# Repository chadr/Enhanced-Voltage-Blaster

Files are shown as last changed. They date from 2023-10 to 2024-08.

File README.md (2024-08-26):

# Enhanced Voltage Blaster
 A (slightly) enhanced version of the original Voltage Blaster by PhilsComputerLab and Necroware [here](https://youtu.be/y1-0giyLQIY).

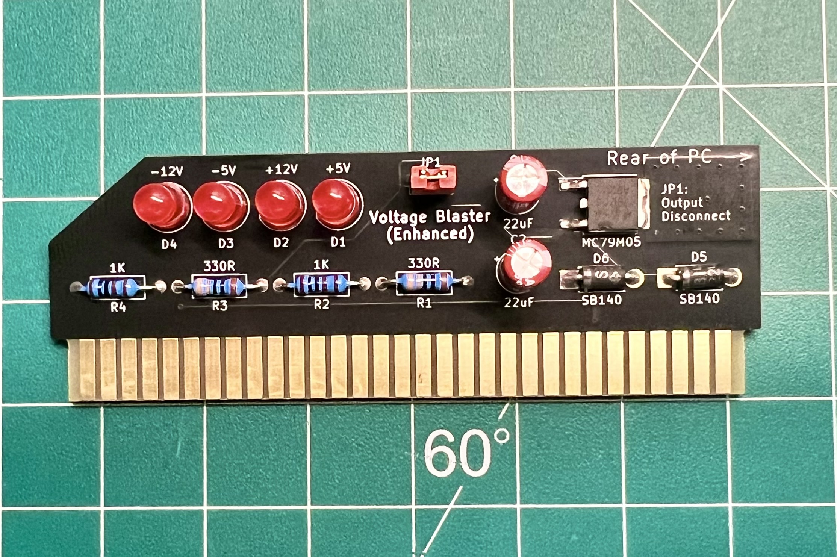
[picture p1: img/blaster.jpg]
Finished Voltage Blaster


**Enhancements:**
* Diodes protect regulator from reverse polarity and reverse bias. Prevents soundcard-frying over voltage.
* Four LEDs show presence of the four main power rails on the ISA bus.
* Dual copper heatsink pads embedded into PCB design to keep regulator cool.
* Jumper to disable Voltage Blaster without removal. Can be used to verify lack of (-)5V on ISA bus.

The datasheet for the 79xx series negative regulators strongly recommend two protection diodes. PCs get shutdown suddenly and sound cards have lots of capacitance. The exact two situations described here.
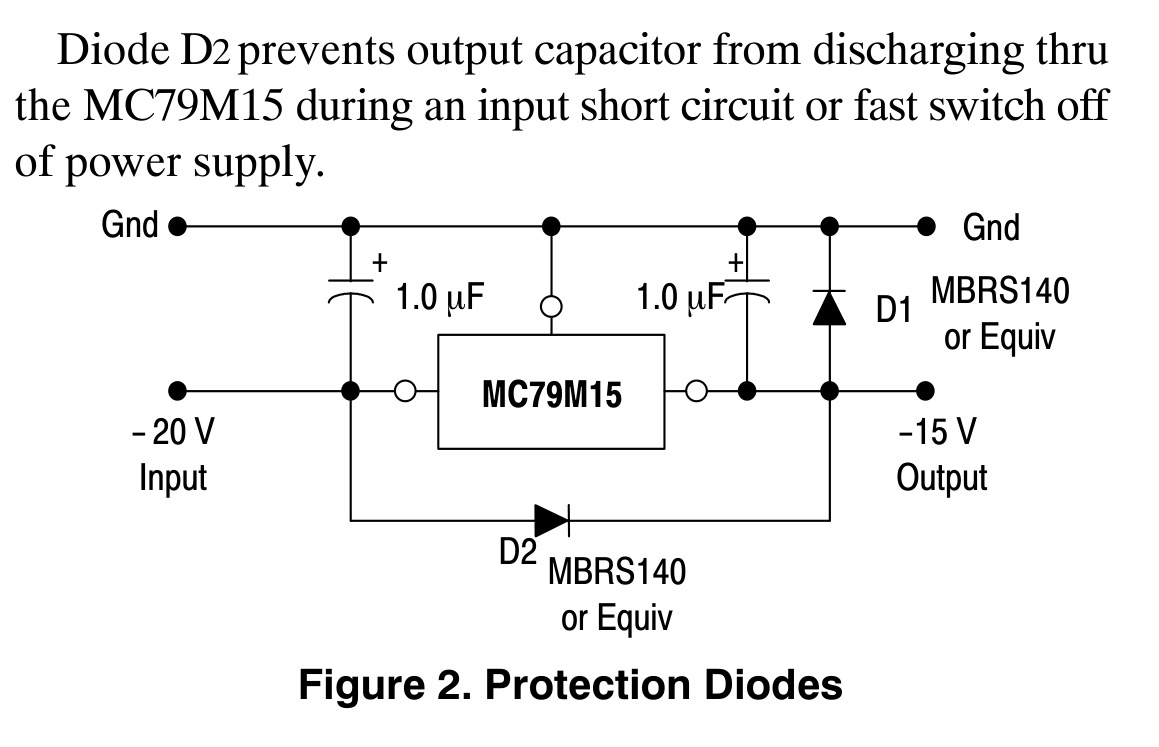
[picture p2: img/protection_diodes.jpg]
Protection diode info


**Bill of Materials**
**Item**|**Qty**|**MFG Part Num**|**Mouser Part Num**
:-----:|:-----:|:-----:|:-----:
Neg 5V Linear Regulator|1|MC79M05CDT|863-MC79M05CDT
22uF 35V Electrolytic Capacitor|2|860010572003|710-860010572003
5mm Red LED Diffused|4|WP7113ID|604-WP7113ID
330R Metal Film Resistor 1%|2|MFR-25FRF52-330R|603-MFR-25FRF52-330R
1K Metal Film Resistor 1%|2|MFR-25FRF52-1K|603-MFR-25FRF52-1K
Schottky Diode 40 Volt 1.0 Amp|2|SB140-E3/73|625-SB140-E3/73



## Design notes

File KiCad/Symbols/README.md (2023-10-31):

# Symbols
A place to store custom Kicad symbols that I have created. Use at your own risk. You should vet your own use of these symbols for suitability and accuracy.

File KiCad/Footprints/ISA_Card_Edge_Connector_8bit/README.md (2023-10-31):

# ISA_Card_Edge_Connector_8bit
A Kicad footprint describing the 8-bit ISA card edge connector.

## Revision 1:
- Added F.Mask and B.Mask areas over card edge fingers, so they do not need to be added manually on a board design.
- Added some distance measurements to the "Eco2.User" layer, as well as a suggested grid spacing, to make it easier to set the edge connector width on the Edge.Cuts layer.

Rev1 Image

## Revision 0:
- First release of the footprint.
- Footprint origin is aligned to the bottom centre of Pad A01 (Pad B01) of the corresponding 8bit ISA card edge connector.
- Board edge guides are on the "Eco1.User" layer. Take care as they are strange decimal fractions.
- Board edge guide duplicated on the "F.Fab" layer adjacent to the card edge connector (can't remember why I did this...)
- See corresponding ISA card edge reference drawing for exact board edge locations.
- Corresponding Keystone 9202 hole location reference shown as a cross in the upper right hand of the symbol on the "Eco1.User" layer.

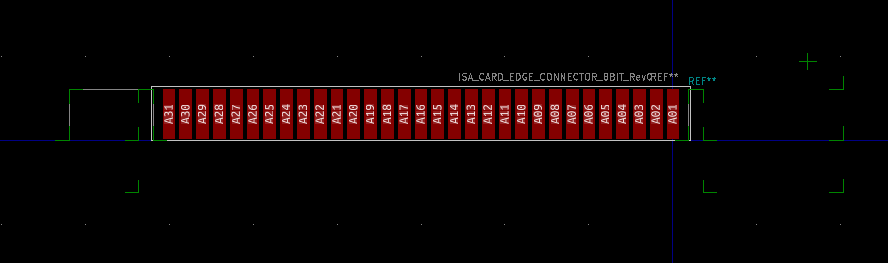
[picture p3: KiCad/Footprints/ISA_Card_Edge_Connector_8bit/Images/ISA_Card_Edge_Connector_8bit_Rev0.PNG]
Rev0 Image


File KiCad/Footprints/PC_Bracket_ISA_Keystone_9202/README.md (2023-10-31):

# PC_Bracket_ISA_Keystone_9202
A Kicad footprint describing the Keystone 9202 mounting bracket, referenced to the bottom of pad A1 of the 8-bit ISA card edge connector.

## Revision 1:
- Added a reference for the location of protruding connectors to the "Cmts.User" layer.
- Added maximum permissible upper board edge reference to the "Eco1.User" layer.

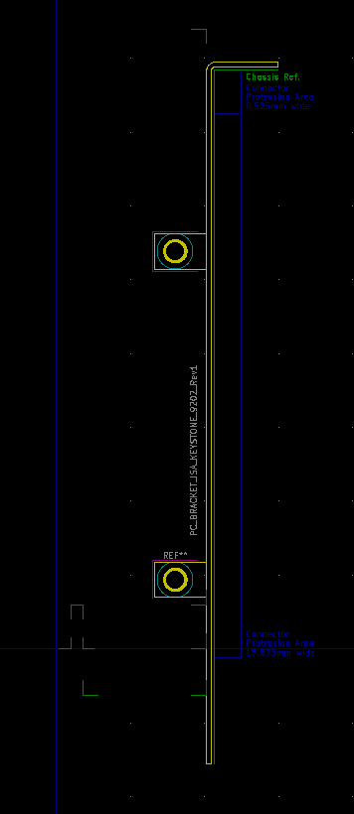
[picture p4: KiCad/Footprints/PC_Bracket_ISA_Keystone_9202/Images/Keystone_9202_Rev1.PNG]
Rev1 Image

## Revision 0:
- First release of the footprint.
- Footprint origin is aligned to the bottom centre of Pad A01 (Pad B01) of the corresponding 8bit ISA card edge connector.
- Board edge guides are on the "Eco1.User" layer. Take care as they are strange decimal fractions.
- See corresponding ISA card edge reference drawing for exact board edge locations.
- Bracket physical outline is on the "Eco2.User" layer.
- Board mounting holes presented as circular plated through holes, 3.2mm dia. "Pin 1" located towards bottom of bracket. "Pin 2" located towards top of bracket. 

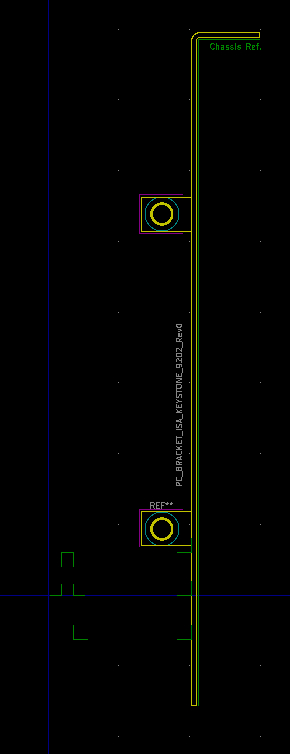
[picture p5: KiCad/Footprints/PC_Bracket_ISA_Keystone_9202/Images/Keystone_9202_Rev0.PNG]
Rev0 Image


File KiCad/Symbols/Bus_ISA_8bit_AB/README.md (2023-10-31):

# Bus_ISA_8bit_AB Symbol
A Kicad symbol for use with the ISA_Card_Edge_Connector_8bit footprint.

## Revision 0:
- First release of the symbol.

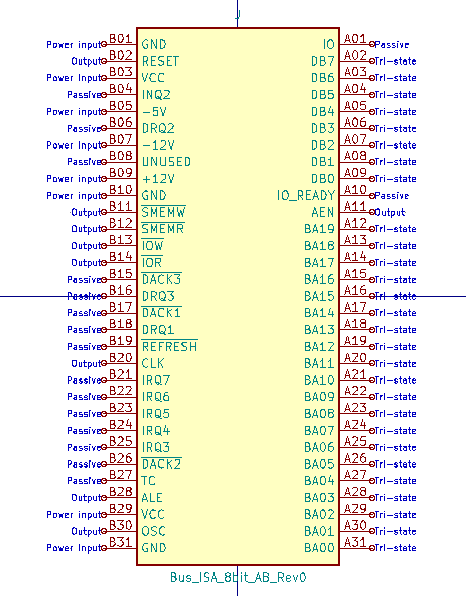
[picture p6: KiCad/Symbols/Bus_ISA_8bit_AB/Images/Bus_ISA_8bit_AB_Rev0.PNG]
Rev0 Image


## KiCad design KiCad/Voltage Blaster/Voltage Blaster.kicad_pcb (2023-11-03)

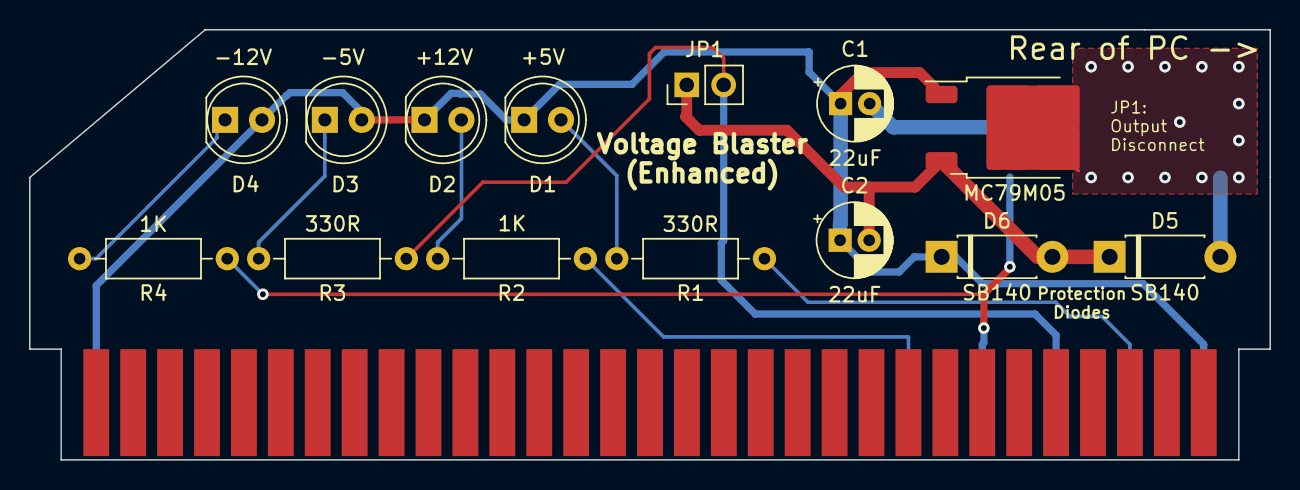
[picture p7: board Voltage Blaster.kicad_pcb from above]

Board: 2 copper layers, 85.3 x 29.6 mm, 16 parts (1 on the bottom side), 10 nets.

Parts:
C1, C2: 22uF; CP_Radial_D5.0mm_P2.00mm
D1: +5V; LED_D5.0mm
D2: +12V; LED_D5.0mm
D3: -5V; LED_D5.0mm
D4: -12V; LED_D5.0mm
D5, D6: SB140; D_DO-41_SOD81_P7.62mm_Horizontal
J1: Bus_ISA_8bit_AB_Rev0; ISA_CARD_EDGE_CONNECTOR_8BIT_Rev1
JP1: Output Disconnect; PinHeader_1x02_P2.54mm_Vertical
Open Hardware Logo: OSHW-Logo2_7.3x6mm_SilkScreen
R1, R3: 330R; R_Axial_DIN0207_L6.3mm_D2.5mm_P10.16mm_Horizontal
R2, R4: 1K; R_Axial_DIN0207_L6.3mm_D2.5mm_P10.16mm_Horizontal
U1: MC79M05; TO-252-2

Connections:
+5V: J1.B03 (VCC), R1.1
+12V: J1.B09 (+12V), R2.1
-5V: J1.B05 (-5V), JP1.2 (B), R3.1
-12V: C1.2, D5.2 (A), J1.B07 (-12V), R4.1, U1.2 (VI)
/VO: C2.2, D5.1 (K), D6.2 (A), JP1.1 (A), U1.3 (VO)
GND: C1.1, C2.1, D1.1 (K), D2.1 (K), D3.2 (A), D4.2 (A), D6.1 (K), J1.B01 (GND), J1.B31 (GND), U1.1 (GND)
unnamed: D1.2 (A), R1.2
unnamed: D2.2 (A), R2.2
unnamed: D3.1 (K), R3.2
unnamed: D4.1 (K), R4.2

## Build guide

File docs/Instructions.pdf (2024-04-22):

## CAUTION: Improper installation could result in damage!

Please follow all instructions carefully.

1. Power off the computer.
2. Insert the Voltage Blaster in a free ISA slot. It can be an 8-bit or 16-bit slot.
3. Make sure the Voltage Blaster is oriented correctly in the ISA slot.

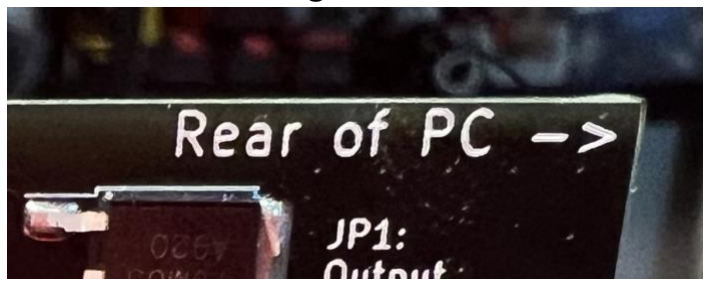
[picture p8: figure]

4. REMOVE the jumper from the Voltage Blaster.
5. Power on your computer.
6. The -5V LED indicator should remain OFF. The other three indicators should be ON. As shown below. This verifies you are missing -5V on the ISA bus. (If all four LEDs are lit with the jumper removed, it means your power supply is putting out -5V and the Voltage Blaster is not necessary.)

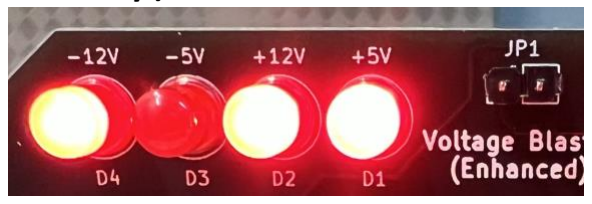
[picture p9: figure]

7. Power off your computer.
8. Reinstall the jumper on the Voltage Blaster.
9. Power on your computer.
10. All four LED indicators should now be on as shown below.

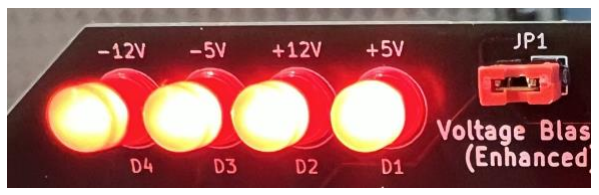
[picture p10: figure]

11.Any ISA cards that require -5V should now work properly. Any motherboard BIOS/POST errors about missing -5V should also go away.
12.Enjoy! Please contact me if you have any questions or problems. chad@pc-resto.com

### Enhanced Voltage Blaster Instructions

Undefined Systems, LLC dba PC Restoration.

https://pc-resto.com https://www.ebay.com/str/pcrestoration

This arrow should point towards the REAR of your computer.
